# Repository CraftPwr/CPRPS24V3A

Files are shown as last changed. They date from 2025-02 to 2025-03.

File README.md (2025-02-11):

# **Craft Power Labs - Open Source Lab Equipment Initiative**  
### **Bench Top Power Supply - CPRPS24V3A**  
An open-source variable lab bench power supply designed for education, hobbyists, and non-profit initiatives. Part of the **Craft Power Labs Initiative**, funded initially by **DERBI / Nidhi Prayas**.  

---

## **📜 Project Overview**  
Craft Power Labs aims to provide accessible, high-quality, and open-source lab equipment for electronics learning and research. This power supply is built to match the essential features of commercial-grade bench power supplies while remaining completely open-source for personal, educational, and non-commercial use.  

---

## **📊 Technical Specifications (Datasheet)**  

| **Feature** | **Specification** |
|---|---|
| **Input Supply** | 110V ~ 220V AC |
| **Variable Voltage** | 0V to 24V |
| **Current Capacity** | Up to 3A |
| **Voltage Resolution**  | 10mV |
| **Current Limit Resolution** | 50mA |
| **Voltmeter Resolution** | 100mV |
| **Ammeter Resolution**  | 100mA |
| **Noise & Ripple (@ 20MHz)** | < 50mV |
| **Operating Modes** | Constant Voltage (CV), Constant Current (CC) |
| **Safety Features** | Over Current, Short Circuit, Reverse Voltage Bypass |
| **Display** | 1-inch Volt-Amp Meter Digits |
| **Control** | Multi-Turn Potentiometers |
| **Connectors** | 4mm Banana Sockets |
| **AC Port** | IEC 14 Port with Illuminated SPST Switch + Fuse |

---

## **📷 Images & Renders**  
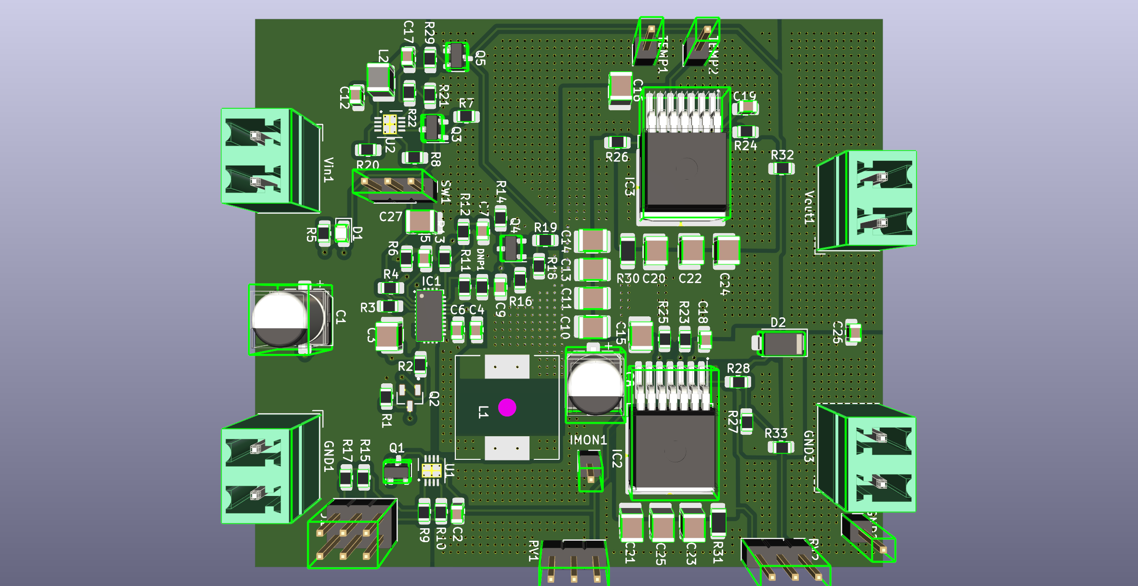
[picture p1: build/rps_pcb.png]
CPRPS25V3A PCB
  

---

## **📜 Licensing**  
This project is licensed under **CC BY-NC-SA 4.0**, which means:  
✔ Free to use, modify, and distribute for personal, educational, and non-commercial purposes.  
✔ Must provide attribution and share derivative works under the same license.  
❌ **Not for commercial use** without explicit permission.  

For more details, see: [LICENSE.md](./LICENSE.md)  

📩 **For inquiries, contact us:**  
**Email:** [connect@craftpower.cc](mailto:connect@craftpower.cc)  
**Website:** [https://craftpower.cc](https://craftpower.cc)  

---

## **🛠 Getting Started**  
### **1️⃣ Hardware Design**  
- Schematic and PCB files are available in the `/hardware` directory.  
- Designed using **KiCad**.  

### **2️⃣ Assembly & Testing**  
- Refer to the `assembly_guide.md` for step-by-step assembly instructions.  
- Use the `calibration_guide.md` to fine-tune voltage and current accuracy.  

---

## **🛠 Contributing**  
We welcome contributions! If you'd like to improve the design, add new features, or fix bugs:  
1. Fork this repository  
2. Create a new branch (`feature-new-component`)  
3. Submit a Pull Request  

---

## **🌍 Join the Community**  
Be part of our mission to make electronics lab equipment open-source and accessible.  

💬 **Join our discussion forum**: [Forum Link]  
📢 **Follow updates**: [Social Media Link]  

---

🚀 **Craft Power Labs - Powering Learning, One Bench at a Time!**

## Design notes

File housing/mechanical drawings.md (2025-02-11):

### **Mechanical Drawings**

### The mechanical drawings provide detailed dimensions and layouts for the CP \- RPS product assembly. These drawings serve as a reference for accurate fabrication, fitting, and alignment of components. The following key elements are included in the mechanical drawings:

#### **1\. Bottom Lid Layout**

* **Mounting Holes**: Exact positions and dimensions for securing the **AC-DC Module** and **DC-DC Module** using **M3 screws**.  
* **Wire Routing Guides**: Markings for optimal placement of wires to avoid overlaps and ensure safety.



#### **2\. Metal Enclosure Design**

* **External Dimensions**: Specifications for the enclosure's height, width, and depth.  
* **Ventilation Slots**: Placement and size of ventilation slots to ensure effective airflow and cooling.  
* **Banana Jack Sockets**: Cutouts and mounting details for the **Banana Jack Sockets**, ensuring proper alignment and access from the enclosure’s exterior.  
* **Cable Entry Points**: Locations for Line and Neutral wire connections to the AC-DC Module.



#### 

#### **3\. Top Lid Design**

* **Fan Mounting**: A detailed layout for mounting the 30mm cooling fan, including hole sizes and screw positions.  
* **Assembly Points**: Precise alignment details for securing the top lid to the metal enclosure with **M3 screws**.



#### **5\. Component Dimensions and Tolerances**

* **AC-DC Module**: Dimensions and mounting positions.  
* **DC-DC Module**: Specifications for dimensions, connectors, wire routing, and auxiliary power supply module attachment.  
* **Banana Jack Sockets**: Position and dimensions for installation on the metal enclosure, ensuring compatibility with the wiring diagram.

These mechanical drawings ensure precision in manufacturing and assembly, reducing the risk of errors and facilitating smooth production.

[image1]: <>

[image2]: <>

[image3]: <>

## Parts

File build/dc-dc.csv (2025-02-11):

null | Sourced | Placed | References | Value | Footprint | Quantity
1 |  |  | C11, C13, C14, C15, C16, C20, C21, C22, C23, C24, C25 | 10uF | C_1210_3225Metric_Pad1.33x2.70mm_HandSolder | 11
2 |  |  | C2, C4, C12, C26 | 1uF | C_0805_2012Metric_Pad1.18x1.45mm_HandSolder | 4
3 |  |  | C5, C6 | 0.1uF | C_0805_2012Metric_Pad1.18x1.45mm_HandSolder | 2
4 |  |  | C18, C19 | 0.01uF | C_0805_2012Metric_Pad1.18x1.45mm_HandSolder | 2
5 |  |  | C1 | 22uF | CP_Elec_6.3x7.7 | 1
6 |  |  | C3 | 10uF 50V | C_1210_3225Metric_Pad1.33x2.70mm_HandSolder | 1
7 |  |  | C7 | (OPT) | C_0805_2012Metric_Pad1.18x1.45mm_HandSolder | 1
8 |  |  | C8 | 100uF | CP_Elec_6.3x7.7 | 1
9 |  |  | C9 | 1nF | C_0805_2012Metric_Pad1.18x1.45mm_HandSolder | 1
10 |  |  | C10 | DNP | C_1210_3225Metric_Pad1.33x2.70mm_HandSolder | 1
11 |  |  | C17 | 10uF | C_0805_2012Metric_Pad1.18x1.45mm_HandSolder | 1
12 |  |  | R7, R13, R16, R23, R24 | 1K | R_0805_2012Metric_Pad1.20x1.40mm_HandSolder | 5
13 |  |  | R8, R25, R26 | 10K | R_0805_2012Metric_Pad1.20x1.40mm_HandSolder | 3
14 |  |  | R1, R11 | 5.1K | R_0805_2012Metric_Pad1.20x1.40mm_HandSolder | 2
15 |  |  | R5, R29 | 549E | R_0805_2012Metric_Pad1.20x1.40mm_HandSolder | 2
16 |  |  | R18, R19 | 100K | R_0805_2012Metric_Pad1.20x1.40mm_HandSolder | 2
17 |  |  | R30, R31 | 10K | R_1206_3216Metric_Pad1.30x1.75mm_HandSolder | 2
18 |  |  | R32, R33 | 0.01E | R_0805_2012Metric_Pad1.20x1.40mm_HandSolder | 2
19 |  |  | R2 | 2.7K | R_0805_2012Metric_Pad1.20x1.40mm_HandSolder | 1
20 |  |  | R3 | 499K | R_0805_2012Metric_Pad1.20x1.40mm_HandSolder | 1
21 |  |  | R4 | 55K | R_0805_2012Metric_Pad1.20x1.40mm_HandSolder | 1
22 |  |  | R6 | 60.4K | R_0805_2012Metric_Pad1.20x1.40mm_HandSolder | 1
23 |  |  | R9 | 200E | R_0805_2012Metric_Pad1.20x1.40mm_HandSolder | 1
24 |  |  | R10 | 47.5K | R_0805_2012Metric_Pad1.20x1.40mm_HandSolder | 1
25 |  |  | R12 | (OPT) | R_0805_2012Metric_Pad1.20x1.40mm_HandSolder | 1
26 |  |  | R14 | 4.99K | R_0805_2012Metric_Pad1.20x1.40mm_HandSolder | 1
27 |  |  | R15 | 73.2K | R_0805_2012Metric_Pad1.20x1.40mm_HandSolder | 1
28 |  |  | R17 | 11.3K | R_0805_2012Metric_Pad1.20x1.40mm_HandSolder | 1
29 |  |  | R20 | 806K | R_0805_2012Metric_Pad1.20x1.40mm_HandSolder | 1
30 |  |  | R21 | 1.47M | R_0805_2012Metric_Pad1.20x1.40mm_HandSolder | 1
31 |  |  | R22 | 280K | R_0805_2012Metric_Pad1.20x1.40mm_HandSolder | 1
32 |  |  | R27 | 3.92K | R_0805_2012Metric_Pad1.20x1.40mm_HandSolder | 1
33 |  |  | R28 | 100E | R_0805_2012Metric_Pad1.20x1.40mm_HandSolder | 1
34 |  |  | L1 | 5.5uH | L_12x12mm_H4.5mm | 1
35 |  |  | L2 | 470uH | L_1210_3225Metric_Pad1.42x2.65mm_HandSolder | 1
36 |  |  | D1 | LED | LED_0805_2012Metric_Pad1.15x1.40mm_HandSolder | 1
37 |  |  | D2 | B140 | D_SMA
Schottky Diode 1A 40V 0.5Vf SMA | Diodes Inc B140-13-F
 | Diodes Inc.
38 |  |  | U1 | LT3092EDD | DFN-8-1EP_3x3mm_P0.5mm_EP1.65x2.38mm_ThermalVias
200mA 2-Terminal Programmable Current Source
 |  | lt3092edd#pbf
39 |  |  | U2 | LTC3632EDD | DFN-8-1EP_3x3mm_P0.5mm_EP1.65x2.38mm_ThermalVias
Buck Switching Regulator IC Positive or Negative Adjustable 0.8V 1 Output 20mA 8-WFDFN Exposed Pad
 |  | ltc3632edd#pbf
40 |  |  | SW1 | SW_SPDT_321 | PinHeader_1x03_P2.54mm_Vertical | 1
41 |  |  | GND1, GND3 | ~ | PhoenixContact_MCV_1,5_2-G-5.08_1x02_P5.08mm_Vertical
PCB Terminal Screw 2.54mm 20AWG 160V 6A 2 Position COMBICON MPT Series | Phoenix Contact 1725656
42 |  |  | GND2, TEMP1 | TestPoint | PinHeader_1x01_P2.54mm_Vertical | 2
43 |  |  | IC2, IC3 | LT3081ER_PBF | TO-263-7_TabPin8
1.5A Single Resistor Rugged Linear Regulator with Monitors
44 |  |  | IMON1, TEMP2 | 10V-40V | PinHeader_1x01_P2.54mm_Vertical | 2
45 |  |  | Q3, Q4 | MMBT3906 | SOT-23-3 | 2
46 |  |  | DNP1 | 5.1K | R_0805_2012Metric_Pad1.20x1.40mm_HandSolder | 1
47 |  |  | IC1 | LT8612EUDE#PBF | QFN-28-1EP_3x6mm_P0.5mm_EP1.7x4.75mm_ThermalVias | 1
48 |  |  | Q1 | SI2309CDS | SOT-23-3
60V 1.6A 1.7W 345mohm @ 10V | Siliconix / Vishay SI2309CDS-T1-E3
 | Vishay Siliconix
49 |  |  | Q2 | CMST3904 | SOT-23-3 | 1
50 |  |  | Q5 | FMMT493 | SOT-23-3 | 1
51 |  |  | RV1 | 10K | PinHeader_1x03_P2.54mm_Vertical | 1
52 |  |  | RV2 | 5K | PinHeader_1x03_P2.54mm_Vertical | 1
53 |  |  | Vin1 | 10V-40V | PhoenixContact_MCV_1,5_2-G-5.08_1x02_P5.08mm_Vertical
PCB Terminal Screw 2.54mm 20AWG 160V 6A 2 Position COMBICON MPT Series | Phoenix Contact 1725656
54 |  |  | Vout1 | 0V-24V | PhoenixContact_MCV_1,5_2-G-5.08_1x02_P5.08mm_Vertical
PCB Terminal Screw 2.54mm 20AWG 160V 6A 2 Position COMBICON MPT Series | Phoenix Contact 1725656
55 |  |  | J1 | Conn_02x03_Odd_Even | PinHeader_2x03_P2.54mm_Vertical | 1

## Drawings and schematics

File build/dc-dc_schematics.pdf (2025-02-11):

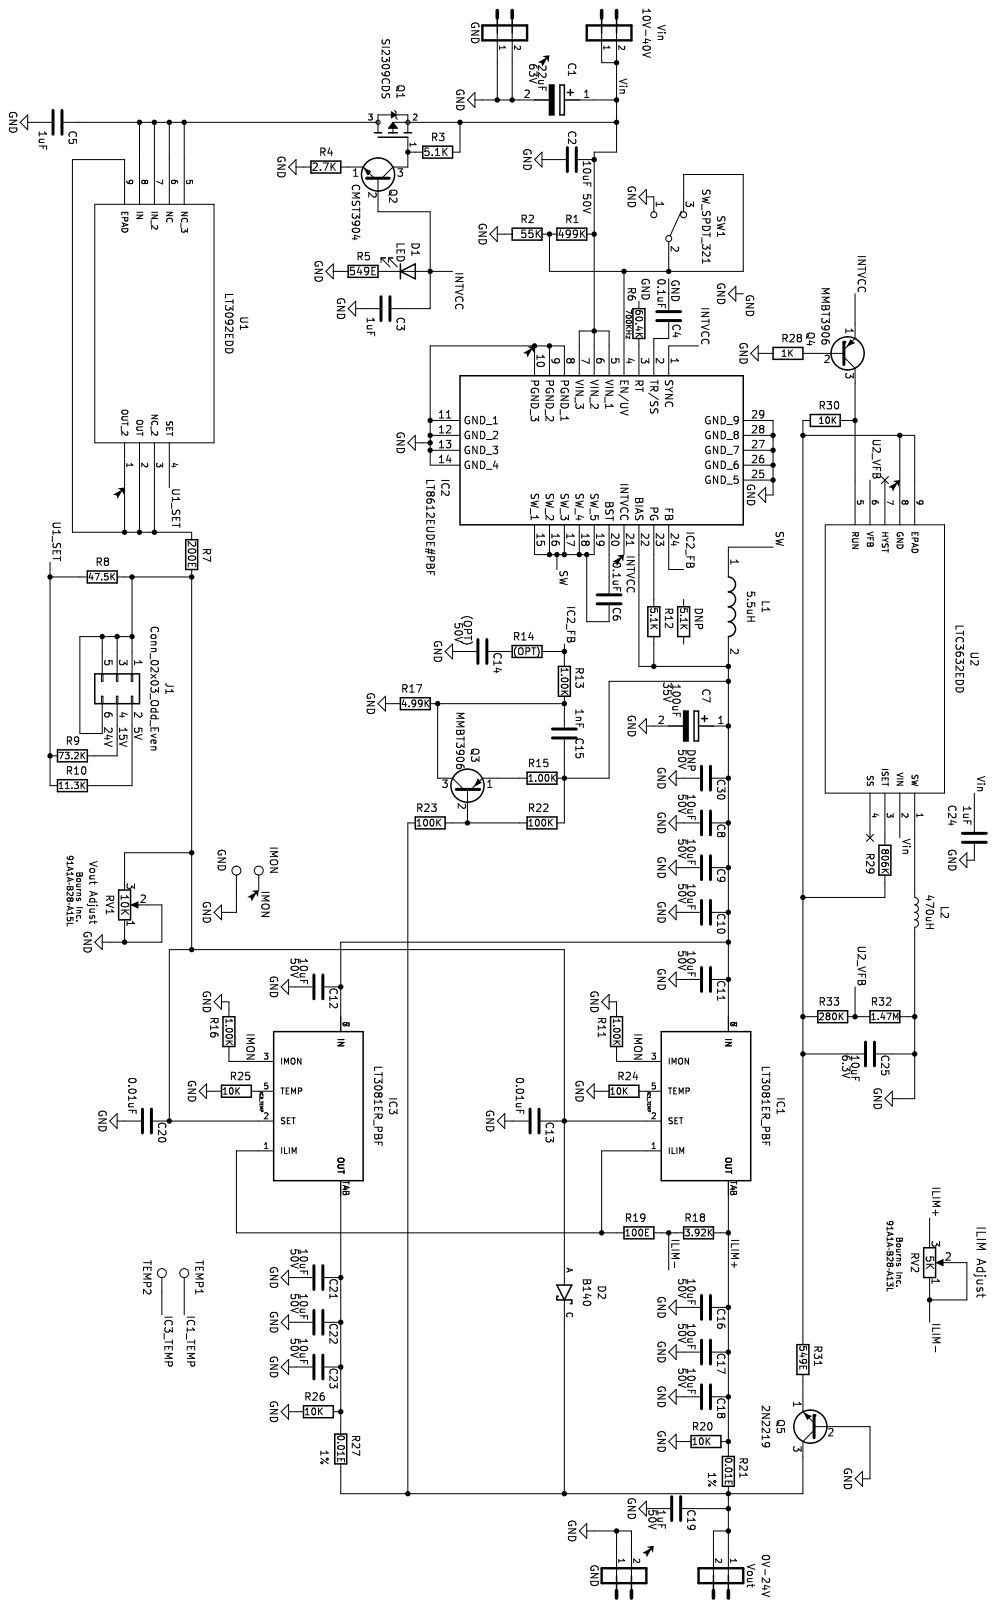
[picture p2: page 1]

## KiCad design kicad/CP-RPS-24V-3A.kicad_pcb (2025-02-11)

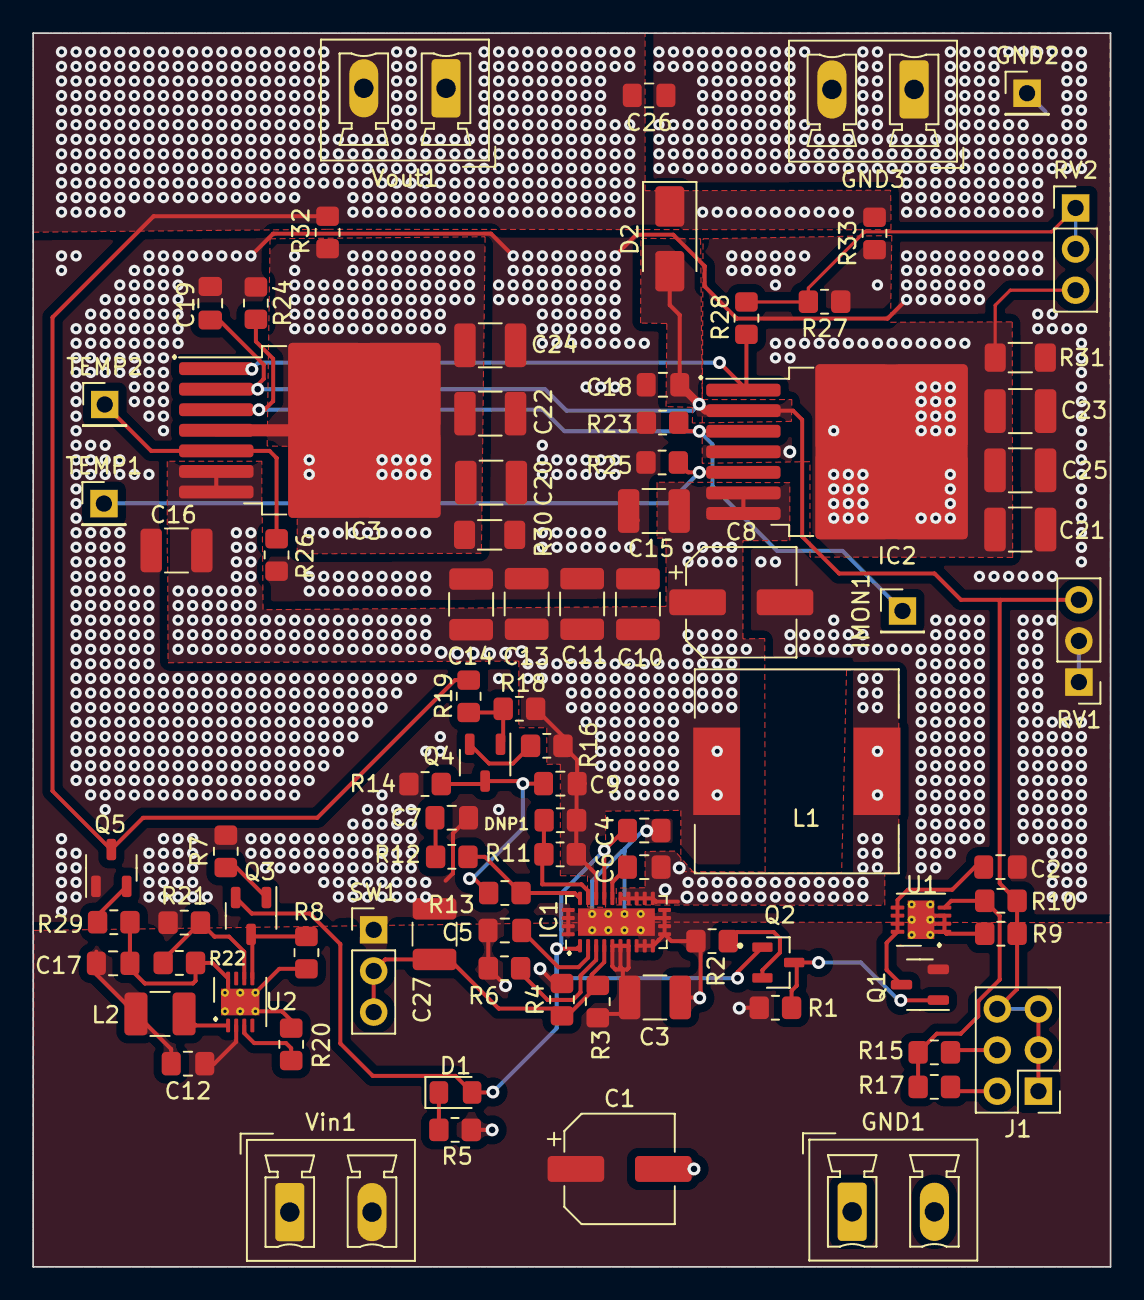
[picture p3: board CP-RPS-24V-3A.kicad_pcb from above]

Board: 2 copper layers, 66.5 x 76.2 mm, 87 parts (0 on the bottom side), 39 nets.

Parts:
C1: 22uF; CP_Elec_6.3x7.7
C2, C4, C12, C26: 1uF; C_0805_2012Metric_Pad1.18x1.45mm_HandSolder
C3: 10uF 50V; C_1210_3225Metric_Pad1.33x2.70mm_HandSolder
C5, C6: 0.1uF; C_0805_2012Metric_Pad1.18x1.45mm_HandSolder
C7: (OPT); C_0805_2012Metric_Pad1.18x1.45mm_HandSolder
C8: 100uF; CP_Elec_6.3x7.7
C9: 1nF; C_0805_2012Metric_Pad1.18x1.45mm_HandSolder
C10: DNP; C_1210_3225Metric_Pad1.33x2.70mm_HandSolder
C11, C13, C14, C15, C16, C20, C21, C22, C23, C24, C25: 10uF; C_1210_3225Metric_Pad1.33x2.70mm_HandSolder
C17: 10uF; C_0805_2012Metric_Pad1.18x1.45mm_HandSolder
C18, C19: 0.01uF; C_0805_2012Metric_Pad1.18x1.45mm_HandSolder
C27: 39.6uF; C_1210_3225Metric_Pad1.33x2.70mm_HandSolder
D1: LED; LED_0805_2012Metric_Pad1.15x1.40mm_HandSolder
D2: B140; D_SMA
DNP1: 5.1K; R_0805_2012Metric_Pad1.20x1.40mm_HandSolder
GND1, GND3: PhoenixContact_MCV_1,5_2-G-5.08_1x02_P5.08mm_Vertical
GND2: TestPoint; PinHeader_1x01_P2.54mm_Vertical
IC1: LT8612EUDE#PBF; QFN-28-1EP_3x6mm_P0.5mm_EP1.7x4.75mm_ThermalVias
IC2, IC3: LT3081ER_PBF; TO-263-7_TabPin8
IMON1: 10V-40V; PinHeader_1x01_P2.54mm_Vertical
J1: Conn_02x03_Odd_Even; PinHeader_2x03_P2.54mm_Vertical
L1: 5.5uH; L_12x12mm_H4.5mm
L2: 470uH; L_1210_3225Metric_Pad1.42x2.65mm_HandSolder
Q1: SI2309CDS; SOT-23-3
Q2: CMST3904; SOT95P230X110-3N
Q3, Q4: MMBT3906; SOT-23-3
Q5: FMMT493; SOT-23-3
R1, R11: 5.1K; R_0805_2012Metric_Pad1.20x1.40mm_HandSolder
R2: 2.7K; R_0805_2012Metric_Pad1.20x1.40mm_HandSolder
R3: 499K; R_0805_2012Metric_Pad1.20x1.40mm_HandSolder
R4: 54.9K; R_0805_2012Metric_Pad1.20x1.40mm_HandSolder
R5, R29: 549E; R_0805_2012Metric_Pad1.20x1.40mm_HandSolder
R6: 60.4K; R_0805_2012Metric_Pad1.20x1.40mm_HandSolder
R7: 1K; R_0805_2012Metric_Pad1.20x1.40mm_HandSolder
R8, R25, R26: 10K; R_0805_2012Metric_Pad1.20x1.40mm_HandSolder
R9: 200E; R_0805_2012Metric_Pad1.20x1.40mm_HandSolder
R10: 47.5K; R_0805_2012Metric_Pad1.20x1.40mm_HandSolder
R12: (OPT); R_0805_2012Metric_Pad1.20x1.40mm_HandSolder
R13, R16, R23, R24: 1.00K; R_0805_2012Metric_Pad1.20x1.40mm_HandSolder
R14: 4.99K; R_0805_2012Metric_Pad1.20x1.40mm_HandSolder
R15: 73.2K; R_0805_2012Metric_Pad1.20x1.40mm_HandSolder
R17: 11.3K; R_0805_2012Metric_Pad1.20x1.40mm_HandSolder
R18, R19: 100K; R_0805_2012Metric_Pad1.20x1.40mm_HandSolder
R20: 806K; R_0805_2012Metric_Pad1.20x1.40mm_HandSolder
R21: 1.47M; R_0805_2012Metric_Pad1.20x1.40mm_HandSolder
R22: 280K; R_0805_2012Metric_Pad1.20x1.40mm_HandSolder
R27: 3.92K; R_0805_2012Metric_Pad1.20x1.40mm_HandSolder
R28: 100E; R_0805_2012Metric_Pad1.20x1.40mm_HandSolder
R30, R31: 10K; R_1206_3216Metric_Pad1.30x1.75mm_HandSolder
R32, R33: 0.01E; R_0805_2012Metric_Pad1.20x1.40mm_HandSolder
RV1: 10K; PinHeader_1x03_P2.54mm_Vertical
RV2: 5K; PinHeader_1x03_P2.54mm_Vertical
SW1: SW_SPDT_321; PinHeader_1x03_P2.54mm_Vertical
TEMP1: TestPoint; PinHeader_1x01_P2.54mm_Vertical
TEMP2: 10V-40V; PinHeader_1x01_P2.54mm_Vertical
U1: LT3092EDD; DFN-8-1EP_3x3mm_P0.5mm_EP1.65x2.38mm_ThermalVias
U2: LTC3632EDD; DFN-8-1EP_3x3mm_P0.5mm_EP1.65x2.38mm_ThermalVias
Vin1: 10V-40V; PhoenixContact_MCV_1,5_2-G-5.08_1x02_P5.08mm_Vertical
Vout1: 0V-24V; PhoenixContact_MCV_1,5_2-G-5.08_1x02_P5.08mm_Vertical

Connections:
/IC1_TEMP: IC2.5 (TEMP), R25.1, TEMP1.1
/IC2_FB: IC1.24 (FB), R12.1, R13.2
/IC3_TEMP: IC3.5 (TEMP), R26.1, TEMP2.1
/ILIM+: C21.2, C23.2, C25.2, IC2.4 (OUT), IC2.TAB (OUT), R27.1, R31.1, R33.2, RV2.3
/ILIM-: R27.2, R28.1, RV2.1, RV2.2
/IMON: IC2.3 (IMON), IC3.3 (IMON), IMON1.1, R23.2, R24.2
/INTVCC: C4.1, D1.2 (A), IC1.1 (SYNC), IC1.21 (INTVCC), Q2.1 (B), Q3.2 (E)
/SW: C6.1, IC1.15 (SW_1), IC1.16 (SW_2), IC1.17 (SW_3), IC1.18 (SW_4), IC1.19 (SW_5), L1.1
/U1_SET: R10.2, R15.2, R17.2, U1.4 (SET)
/U2_VFB: R21.2, R22.1, U2.6 (VFB)
/Vin: C1.1 (+), C3.1, C12.1, IC1.5 (VIN_1), IC1.6 (VIN_2), IC1.7 (VIN_3), Q1.2, R1.1, R3.1, U2.2 (VIN), Vin1.1, Vin1.2
GND: C1.2 (-), C2.2, C3.2, C4.2, C5.2, C7.1, C8.2 (-), C10.1, C11.1, C12.2, C13.1, C14.1, C15.1, C16.1, C17.2, C18.1, C19.1, C20.1, C21.1, C22.1, C23.1, C24.1, C25.1, C26.1, C27.2, GND1.1, GND1.2, GND2.1, GND3.1, GND3.2, IC1.8 (PGND_1), IC1.9 (PGND_2), IC1.10 (PGND_3), IC1.11 (GND_1), IC1.12 (GND_2), IC1.13 (GND_3), IC1.14 (GND_4), IC1.25 (GND_5), IC1.26 (GND_6), IC1.27 (GND_7), IC1.28 (GND_8), IC1.29 (GND_9), L2.2, Q5.1 (B), R2.2, R4.2, R5.2, R6.2, R7.2, R14.2, R21.1, R23.1, R24.1, R25.2, R26.2, R30.2, R31.2, RV1.1, RV1.2, SW1.1 (C)
unnamed: C7.2, R12.2
unnamed: C8.1 (+), C9.1, C10.2, C11.2, C13.2, C14.2, C15.2, C16.2, DNP1.1, IC1.22 (BIAS), IC2.6 (IN), IC2.7 (IN), IC3.6 (IN), IC3.7 (IN), L1.2, R11.1, R16.1, R18.1
unnamed: C20.2, C22.2, C24.2, IC3.4 (OUT), IC3.TAB (OUT), R30.1, R32.2
unnamed: D1.1 (K), R5.1
unnamed: C18.2, C19.2, D2.2 (A), IC2.2 (SET), IC3.2 (SET), J1.1, J1.3, J1.5, J1.6, R9.1, R10.1, RV1.3
unnamed: C26.2, D2.1 (K), Q5.3 (C), R19.2, R32.1, R33.1, Vout1.1, Vout1.2
unnamed: C6.2, IC1.20 (BST)
unnamed: C27.1, IC1.4 (EN/UV), R3.2, R4.1, SW1.2 (B), SW1.3 (A)
unnamed: DNP1.2, IC1.23 (PG), R11.2
unnamed: IC1.3 (RT), R6.1
unnamed: C5.1, IC1.2 (TR/SS)
unnamed: IC2.1 (ILIM), IC3.1 (ILIM), R28.2
unnamed: J1.2, R17.1
unnamed: J1.4, R15.1
unnamed: Q1.1, Q2.3 (C), R1.2
unnamed: Q2.2 (E), R2.1
unnamed: Q3.1 (B), R7.1
unnamed: Q3.3 (C), R8.1, U2.5 (RUN)
unnamed: Q4.1 (B), R18.2, R19.1
unnamed: C9.2, Q4.3 (C), R13.1, R14.1
unnamed: Q4.2 (E), R16.2
unnamed: Q5.2 (E), R29.1
unnamed: R9.2, U1.1 (OUT_2), U1.2 (OUT), U1.3 (NC_2), U1.9 (EPAD)
unnamed: C2.1, Q1.3, U1.5 (NC_3), U1.6 (NC), U1.7 (IN_2), U1.8 (IN)
unnamed: C17.1, R8.2, R20.2, R22.2, R29.2, U2.8 (GND), U2.9 (EPAD)
unnamed: R20.1, U2.3 (ISET)
unnamed: L2.1, U2.1 (SW)

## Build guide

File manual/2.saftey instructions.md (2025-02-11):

**Safety Instructions**  
**General Precautions**

* Always disconnect the power supply from the AC mains before performing assembly, maintenance, or component replacement.  
* Ensure the device is properly grounded via the IEC connector’s Earth (E) terminal to prevent electric shock.  
* Avoid operating the unit in wet, humid, or conductive environments.

**High-Voltage Handling**

* The AC-DC Module operates at 230V AC. Only trained personnel should handle live circuits.  
* Use insulated tools and wear protective gloves when working on high-voltage sections.  
* Verify all AC wiring (Line, Neutral, Earth) is securely connected and insulated before powering the unit.

**Component Handling**

* Electrostatic Discharge (ESD) Precautions:  
* Use ESD-safe workstations, wrist straps, and mats when handling sensitive components (e.g., ICs like LT3081ER\_PBF, LT8612EUDE\#PBF).  
* Store ICs and transistors (e.g., MMBT3906, FMMT493) in anti-static packaging.  
* Avoid mechanical stress on surface-mount components (e.g., 0805/1210 resistors, capacitors).

**Thermal Safety**

* The DC-DC Converter and LDO modules may generate heat during operation.  
* Ensure the 30mm cooling fan is functional and unobstructed.  
* Do not block ventilation slots on the metal enclosure.

**Fuse Replacement**

* Replace the fuse only with the specified rating (see production document).  
* Never bypass the fuse or use a higher-rated fuse, as this compromises overload protection.

**Testing and Debugging**

* Use a multimeter to confirm no short circuits between power rails (e.g., \+36V, \-5V, GND) before initial power-up.  
* During load testing, ensure output terminals (Banana Jack Sockets) are not accidentally shorted.  
* Monitor the Volt-Amp Meter for abnormal readings (e.g., sudden voltage drops or current spikes).

**Compliance and Certification**

* Assemble the unit in compliance with regional electrical safety standards (e.g., IEC 61010, UL 61010-1).  
* Verify all protective earth connections and insulation resistance before final packaging.

**Emergency Procedures**

* In case of smoke, sparks, or unusual odors:  
  * Immediately disconnect the power supply.  
  * Do not attempt repairs while the unit is energized.  
* Keep a Class C fire extinguisher nearby for electrical fires.

**User Training**

* Personnel involved in assembly/testing must be trained in:  
  * Basic electrical safety protocols.  
  * Proper use of multimeters, oscilloscopes, and load testers.  
  * Emergency shutdown procedures.

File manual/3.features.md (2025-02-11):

**Features**

### **System Overview**

The CP \- RPS (Compact Precision Regulated Power Supply) is a high-performance power supply designed for laboratory, prototyping, and industrial applications. It provides precise voltage and current regulation, ensuring stable power delivery with advanced protection and diagnostic features.

This power supply system integrates all functional modules into a single unit for reliable and configurable power output.

### **High-Level Features**

* **Voltage and Current Regulation:** Supports output up to **24V and 3A** with fine-tuning from **100mV & 50mA**  
* **Constant Voltage (CV) & Constant Current (CC) Mode:** Automatically switches between modes to ensure stable operation  
* **Advanced Self-Diagnostic Capability:** Continuously monitors system health and detects faults  
* **Integrated Power Design:** All power regulation components are combined into a single DC-DC module  
* **User Interface & Control:** Fine control of voltage and current with high-precision adjustment  
* **Protection Mechanisms:** Includes over-voltage, over-current, over-temperature, and short-circuit protection  
* **Thermal Management:** Efficient heat dissipation with built-in cooling measures  
* **High Efficiency & Stability:** Optimized power conversion with minimal ripple and noise

### **Applications**

With its robust design and flexible features, the CP \- RPS is suitable for:

* **Electronics R\&D and Prototyping**  
* **Embedded System Development**  
* **Testing and Calibration of Electronic Circuits**  
* **Powering Precision Electronics and Sensors**  
* **Industrial and Laboratory Use**

### 

### 

### **Hardware Overview**

#### **Board Design**

The CP \- RPS integrates all power regulation and control circuitry into a well-structured PCB layout, ensuring high efficiency and reliable operation.

#### **Power Modules**

* **AC-DC Converter:** Provides initial power conversion from mains supply  
* **DC-DC Converter:** Single-board implementation for efficient voltage step-down/up (not modular)  
  * **LDO (Low Dropout Regulator):** Ensures stable voltage output with minimal fluctuations  
  * **\-5V Regulator:** Supports applications requiring negative voltage  
  * **Current Source:** Precisely regulates output current for CC mode

#### **Monitoring**

* **Feedback Loop Mechanism:** Provides real-time adjustments for stable operation  
* **Multi-Stage Protection System:** Ensures safe and reliable performance

### **Power Connectors & Wiring**

* High-quality connectors ensure secure and stable power transmission  
* Supports modular wiring for easy assembly and maintenance  
* Integrated safety mechanisms to prevent accidental shorts and overloads

### **Communication and Interface**

* **User Interface:** Intuitive control panel for precise adjustments  
* **Digital Display:** Real-time monitoring of voltage and current

The CP \- RPS is a **versatile and high-precision regulated power supply**, making it a reliable choice for professionals and hobbyists in electronics and industrial applications.

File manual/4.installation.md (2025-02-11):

### **Assembly Instructions**

To ensure a seamless installation and error-free assembly, follow the instructions below:

1. **Connection of AC-DC and DC-DC Modules**  
   * Use **0.5 sq mm multi-strand copper wire** to connect the **positive (+)** and **negative (-)** terminals of the **AC-DC Module** to the **DC-DC Module**.  
2. **Mounting the AC-DC and DC-DC Modules**  
   * Secure the **AC-DC Module** and **DC-DC Module** to the bottom lid using **M3 screws**, ensuring a firm fit.  
3. **Connecting IEC Connector, Switch, and Fuse Holder**  
   * Assemble the **IEC Connector**, **Switch**, and **Fuse Holder** as per the provided wiring diagram.  
   * After completing the connections, identify the two unconnected wires, designated as **Line** and **Neutral**.  
4. **Assembling the Metal Enclosure**  
   * Place the **Metal Enclosure** over the bottom lid and fasten it securely using screws.  
5. **Connecting Line and Neutral Wires**  
   * Attach the **Line** and **Neutral** wires from the **Metal Enclosure** to the **AC-DC Module** terminals.  
6. **Wiring the Base Board**  
   * Connect wires from the **Base Board** to the **Banana Jack Socket** and the **Volt-Amp Meter** as per the wiring diagram.  
7. **Installing the Cooling Fan**  
   * Mount the **30mm fan** onto the top lid and connect its wires to the designated **Base Board connector**.  
8. **Connecting the Auxiliary Power Supply Module**  
   * Attach the **Auxiliary Power Supply Module** to the **Base Board** as specified.  
9. **Final Assembly**  
   * Place the **Top Lid** onto the **Metal Enclosure** and secure it tightly using **M3 screws** to complete the assembly.

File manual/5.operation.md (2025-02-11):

### **Operation**

After completing the assembly of the CP \- RPS, line testing ensures the functionality, reliability, and safety of the product. Follow the steps below to conduct a thorough line test:

#### **1\. Visual Inspection**

* Verify that all components are securely fastened, including the **AC-DC Module**, **DC-DC Module**, and **Banana Jack Sockets**.  
* Ensure all wiring connections are made as per the provided diagrams, with no loose or exposed wires.  
* Confirm that the ventilation slots and fan are unobstructed to allow proper airflow.

#### **2\. Short Circuit Check**

* Before powering on the device, use a multimeter in continuity mode to check for any unintended short circuits across:  
  * **Line and Neutral terminals** of the **AC-DC Module**.  
  * Output terminals of the **DC-DC Module** and **Banana Jack Sockets**.  
  * Connections to the **Volt-Amp Meter** and other components.

#### **3\. Continuity Test**

* Use a multimeter to check continuity for the following connections:  
  * **Line and Neutral Wires**: Ensure proper connection to the **AC-DC Module**.  
  * **Banana Jack Sockets**: Verify correct wiring from the **DC-DC Module**.  
  * **Volt-Amp Meter**: Ensure the connection is as per the wiring diagram.

#### **4\. Power-On Testing**

* Plug the device into an AC mains supply (230V).  
* Turn on the power switch and observe the following:  
  * The fan starts operating.  
  * The Volt-Amp Meter displays initial readings.  
* Ensure there are no unusual sounds, excessive heat, or visible sparks.

#### **5\. Output Voltage and Current Testing**

* Adjust the potentiometer on the **LDO Module** to set the desired voltage and current.  
* Measure the output at the **Banana Jack Sockets** using a multimeter.  
* Confirm that the voltage and current match the expected values for both **Constant Voltage (CV)** and **Constant Current (CC)** modes.

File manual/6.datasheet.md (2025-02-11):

**CP-RPS-24V-2A Datasheet**  
Regulated Power Supply (Version 1.0)

**Overview**  
The CP-RPS is a high-performance regulated power supply designed for applications requiring a stable and adjustable power output of up to 24V and 3A. It features a modular architecture for easy maintenance, self-diagnostic capabilities, and support for both Constant Voltage (CV) and Constant Current (CC) modes. The design emphasizes user convenience, reliability, and safety, making it suitable for a wide range of industrial, educational, and laboratory applications.

**Key Features**  
**Output Voltage Range:** 0V to 24V (adjustable)

**Output Current Range:** 0A to 3A (adjustable)

**Modes of Operation:** Constant Voltage (CV) and Constant Current (CC)

**Self-Diagnostic Capability:** Fault identification for efficient troubleshooting

**Modular Design:** Easy replacement of components

**Input Voltage:** 110V/230V AC 50/60Hz

**Cooling System:** 30mm DC fan for thermal management

**Display:** Integrated Volt-Amp Meter for real-time monitoring

**Safety Features:** Fuse protection, short-circuit protection, and grounding

**Specifications**  
**Electrical Specifications**

| Parameter | Value |
| ----- | ----- |
| Input Voltage	 | 100V/230V AC, 50/60Hz |
| Output Voltage Range | 0V to 24V (adjustable) |
| Output Current Range | 0A to 3A (adjustable) |
| Voltage Resolution | 100mV |
| Current Resolution | 50mA |
| Regulation Accuracy | ±1% |
| Ripple and Noise | \<50mV (peak-to-peak) |
| Efficiency | \>85% |

**Absolute Maximum Ratings**

| Parameter | Value |
| :---- | :---- |
| Input Voltage | 230V AC ±10% |
| Output Voltage | 24V (Max) |
| Output Current | 3A (Max) |
| Operating Temperature | 0°C to 40°C |
| Storage Temperature | \-20°C to 70°C |

**Mechanical Specifications**

| Parameter | Value |
| :---- | :---- |
| Enclosure Material | Sheet Metal |
| Dimensions (L x W x H) | 9.8 x 9.8 x 9.8 cm |
| Weight | 3 Kgs |
| Cooling | 30mm DC Fan (5V) |
| Connectors | Banana Jack Sockets (4mm) |

**Safety and Compliance**  
**Safety Standards:** Complies with \[Insert Relevant Standards\].

**Protection Features:** Overload, short-circuit, and over-temperature protection.

**Grounding:** Properly grounded for user safety.

**Ordering Information**  
**Model Description**

| CP-RPS-24V-3A | Regulated Power Supply, 24V, 3A |
| :---- | :---- |

**Support and Warranty**  
**Warranty Period:** 1 year from the date of purchase.

**Support:** Open Source Design (can be found on GitHub).

**Note:** Specifications and features are subject to change without prior notice. Always refer to the latest documentation for accurate information.

**End of Datasheet**

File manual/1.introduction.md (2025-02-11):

**CP \- RPS**  
**Production Document**

The CP \- RPS represents the first version of the Regulated Power Supply, specifically designed for applications requiring a stable power supply of up to 24V and 3A.

This design emphasizes user convenience by incorporating a modular architecture that enables easy replacement of damaged components. The straightforward and user-friendly layout enhances accessibility and usability, providing a seamless experience for operators.

**The following are the specs of CP \- RPS**

* Voltage: 24V  
* Current: 3A  
* Self-Diagnostic Capability  
* Constant Current (CC) and Constant Voltage (CV) Modes  
* Tuning from 100mV & 50mA

****

[image1]: <>

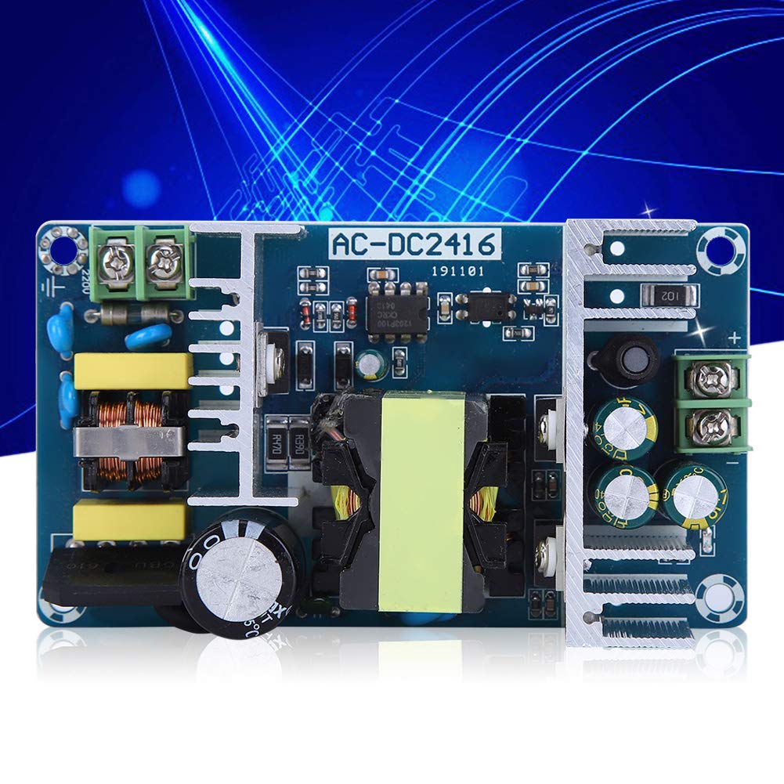
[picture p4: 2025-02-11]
build/ac-dc_module.jpg

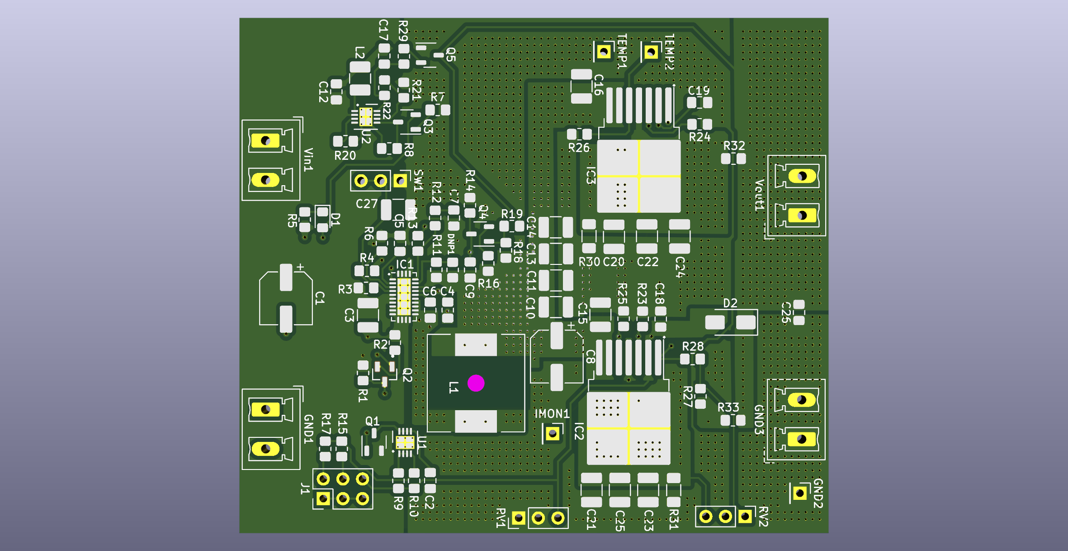
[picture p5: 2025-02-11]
build/dc-dc_pcb.png

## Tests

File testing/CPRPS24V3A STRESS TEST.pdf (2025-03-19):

Craft Power - Nidhi Prayas Milestone 1 Pre-read

## Testing:

Test Equipment:

- Multimeter
- Electronic Load 180W
- Regulated Power Supply (RPS) 0 to 30V

Test Cases:
Functional Test of DCDC Module (Voltage Range):
- Varying resolution (10mV) up to 24V.

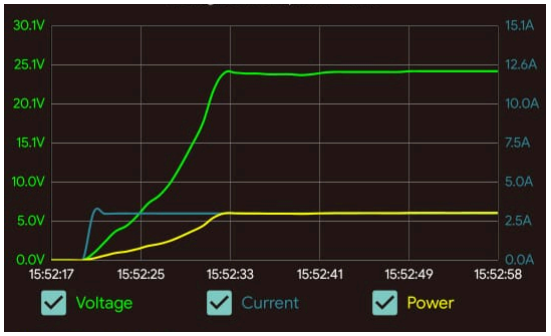
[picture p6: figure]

Functional Test of DCDC Module (Current Range):
- Varying current (100mA steps) up to 3 Amps.

Continuous Loading Test:
- Loading the module to 3 Amps at 24V, monitoring temperature, voltage, and current variations over x hours.

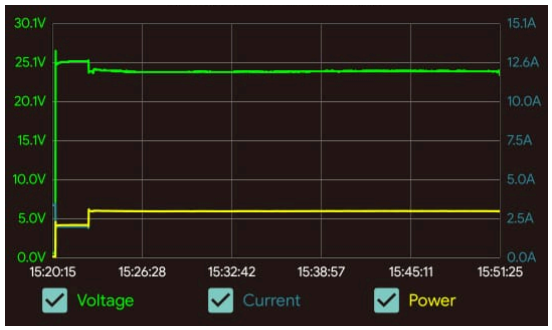
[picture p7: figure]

Craft Power - Nidhi Prayas Milestone 1 Pre-read

Line Regulation Test:
- Monitoring set voltage, output voltage, and voltage difference for every 100mV from 0V to 24V.
- TBD
Load Regulation Test:
- Monitoring set voltage, output voltage, current, temperature, and voltage difference for every 500mA steps from 0 to 3 Amps. Tables for each current with 24 readings.
- TBD
- Short Circuit Test - TBD
- Gradual Overloading Test - Done Pass
- Sudden Overloading Test - Done Pass
- Validation of CV Mode - Done Pass
- Validation of CC Mode - Done Pass

Test Setup Equipment:
Each test case was conducted using the specified equipment in a controlled environment to ensure accuracy and consistency in results.

Craft Power's meticulous approach to prototype development and testing ensured thorough validation of the power supply system's functionality, performance, and reliability, laying the foundation for subsequent refinement and optimization efforts.

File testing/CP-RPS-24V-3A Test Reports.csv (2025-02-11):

Voltage Stability Test - Loaded
Set Voltage = 0.7 |  |  |  | Set Voltage = 1V |  |  |  | Set Voltage = 2V |  |  |  | Set Voltage = 3V |  |  |  | Set Voltage = 4V |  |  |  | Set Voltage = 5V |  |  |  | Set Voltage = 6V |  |  |  | Set Voltage = 7V |  |  |  | Set Voltage = 8V |  |  |  | Set Voltage = 9V |  |  |  | Set Voltage = 10V |  |  |  | Set Voltage = 11V
Input Voltage | Set Voltage | Voltage [Meter] | Current | Input Voltage | Set Voltage | Voltage [Meter] | Current | Input Voltage | Set Voltage | Voltage [Meter] | Current | Input Voltage | Set Voltage | Voltage [Meter] | Current | Input Voltage | Set Voltage | Voltage [Meter] | Current | Input Voltage | Set Voltage | Voltage [Meter] | Current | Input Voltage | Set Voltage | Voltage [Meter] | Current | Input Voltage | Set Voltage | Voltage [Meter] | Current | Input Voltage | Set Voltage | Voltage [Meter] | Current | Input Voltage | Set Voltage | Voltage [Meter] | Current | Input Voltage | Set Voltage | Voltage [Meter] | Current | Input Voltage | Set Voltage | Voltage [Meter] | Current
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
